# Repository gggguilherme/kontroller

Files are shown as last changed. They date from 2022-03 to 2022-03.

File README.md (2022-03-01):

# kontroller
 
this project is -getting on it's paces but hang in there, there's lots of work to do-
#
so proceed with caution and a lot of things might change

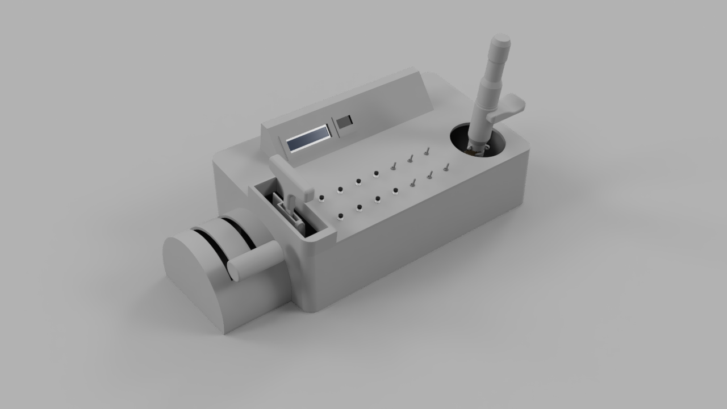
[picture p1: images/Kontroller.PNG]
Kontroller


# References
- [kRPC mod](https://www.github.com/krpc/krpc)
- [kOS mod](https://github.com/KSP-KOS/KOS)
- [LCD Display 3D Model](https://grabcad.com/library/16-x-2-lcd-display-module)
- [OLED Display 3D Model](https://grabcad.com/library/oled-128-x-64-display-1)
- [14 Segment Numerical Display 3D Model](https://grabcad.com/library/dual-digit-numeric-display-dc56-11-or-da56-11-1)
- [Trimmer Potentiometer 3D Model](https://grabcad.com/library/potentiometer-12)
- [Switch 3D Model 1](https://grabcad.com/library/small-power-switches-rocker-type-10-5x15mm-1)
- [Switch 3D Model 2](https://grabcad.com/library/spdt-print-toggle-switch-pcb-mount-1)
- [Buttons 3D Model](https://grabcad.com/library/lockless-on-off-push-button-switch-press-reset-switch-pbs-110-1)
- [G-Clamp 3D Model Thingiverse](https://www.thingiverse.com/thing:1673030)
- [Open Joystick](https://github.com/bhowiebkr/open-joystick)
(I took some ideas from open-joystick to design my stuff, it ended up being completely different, BUT I'd still like to share it because it's really cool and I learned stuff)

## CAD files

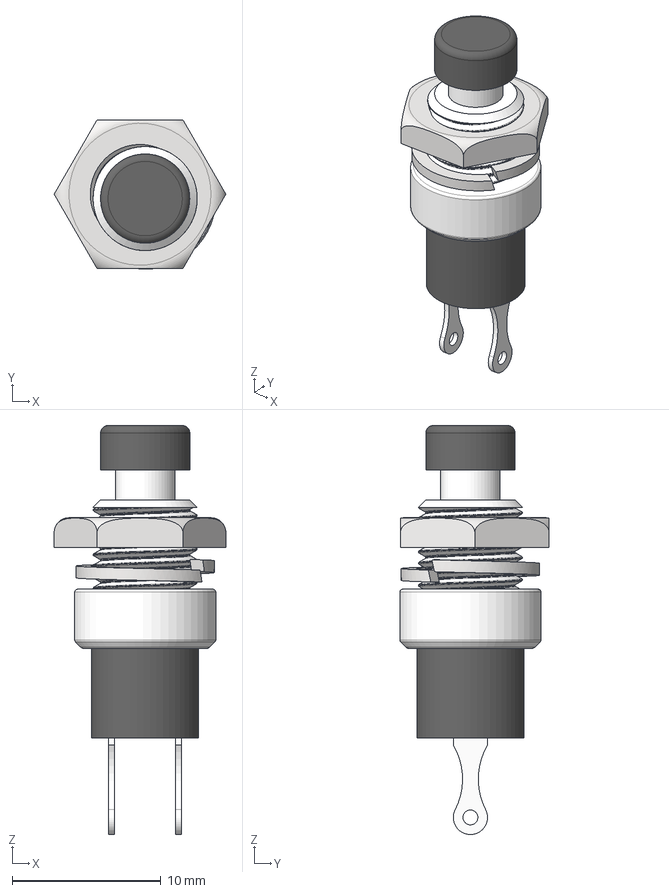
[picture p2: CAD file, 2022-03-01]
Source/3D Models/STEP/Imports/Push button Switch Press reset switch PBS-110.stp
11.5 x 10.0 x 27.5 mm
Self reset PBS-110 7mm Momentary Push button Switch
Nut_M7x0.75
Spring

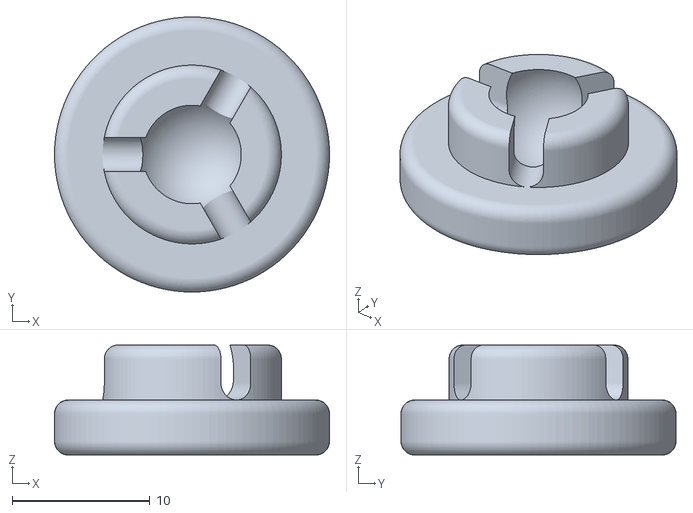
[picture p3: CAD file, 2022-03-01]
Source/3D Models/stl/3D Printed Clamp/clamp_protector.stl
20.0 x 20.0 x 8.00

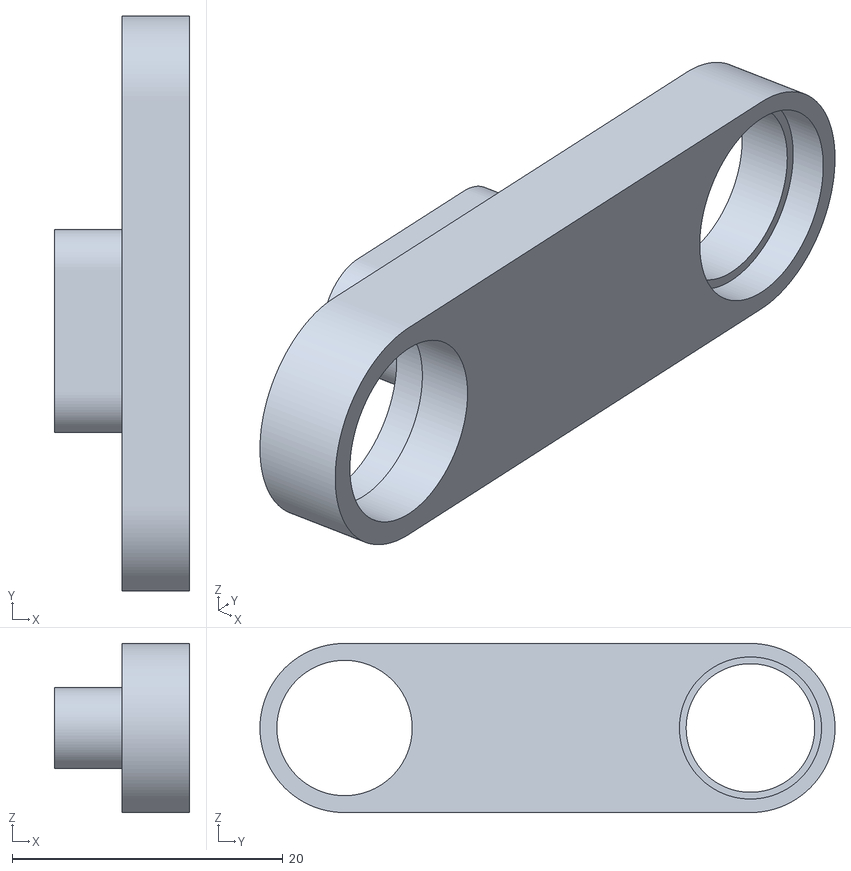
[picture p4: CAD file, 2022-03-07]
Source/3D Models/stl/Throttle Lever/Interface1.stl
10.0 x 42.5 x 12.5

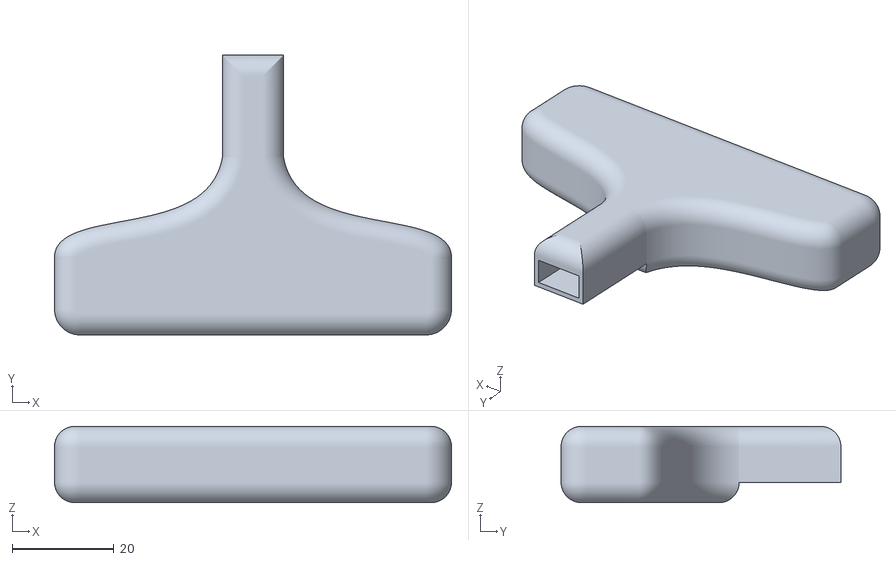
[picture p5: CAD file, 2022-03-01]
Source/3D Models/stl/Translation Control/Handle.stl
78.0 x 55.0 x 15.0

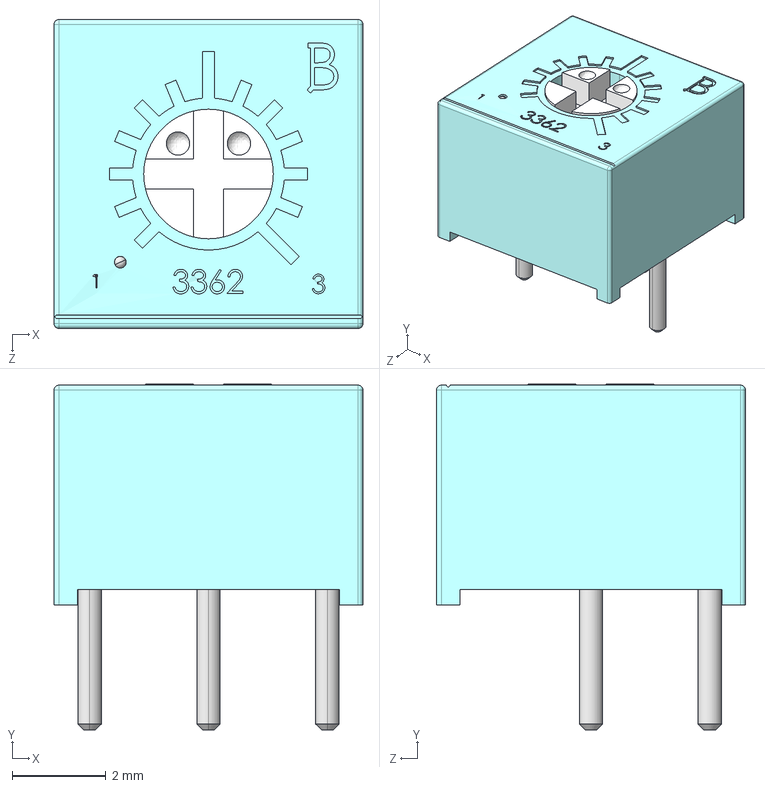
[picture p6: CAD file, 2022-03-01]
Source/3D Models/STEP/Imports/3362P-1-102LF.STEP
6.60 x 7.40 x 6.60 mm

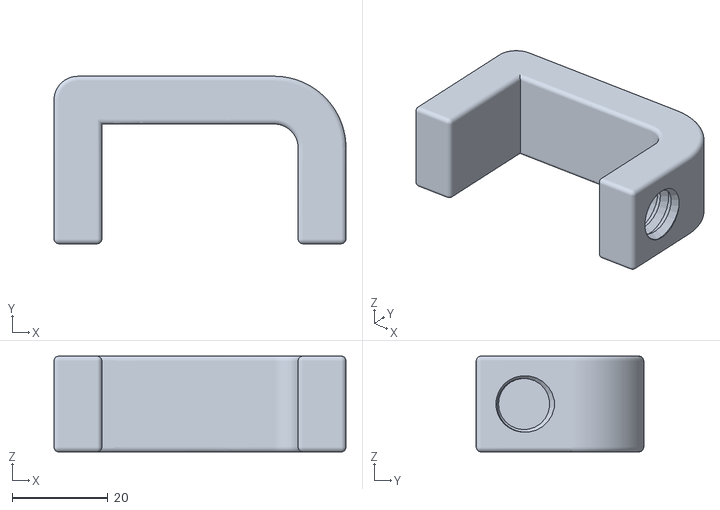
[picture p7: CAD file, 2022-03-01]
Source/3D Models/stl/3D Printed Clamp/clamp_frame.stl
61.0 x 35.0 x 20.0

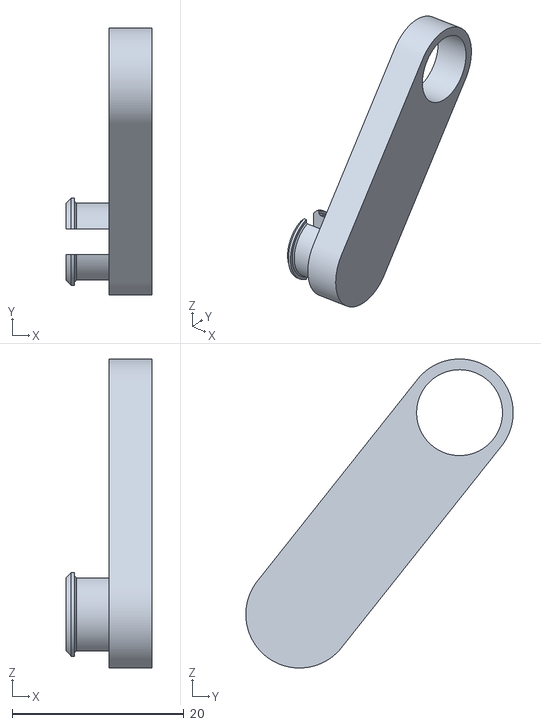
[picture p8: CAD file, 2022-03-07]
Source/3D Models/stl/Throttle Lever/Interface2.stl
10.0 x 31.2 x 36.0

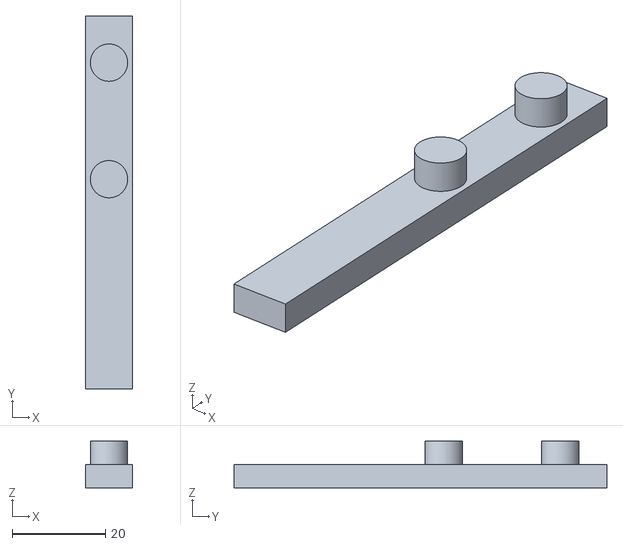
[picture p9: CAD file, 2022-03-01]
Source/3D Models/stl/Translation Control/X-Y Drive.stl
10.0 x 80.0 x 10.0

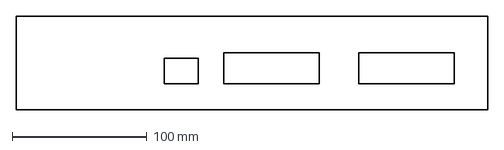
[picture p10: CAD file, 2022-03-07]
Source/Laser Cutting Files/Panel.dxf
350.0 x 69.3 mm

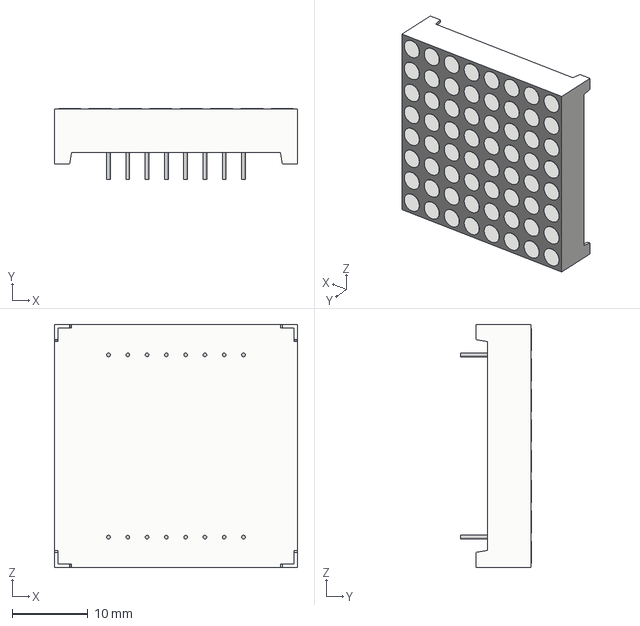
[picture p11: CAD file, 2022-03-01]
Source/3D Models/STEP/Imports/LED Matrix 3mm 8x8.step
32.0 x 9.30 x 32.0 mm

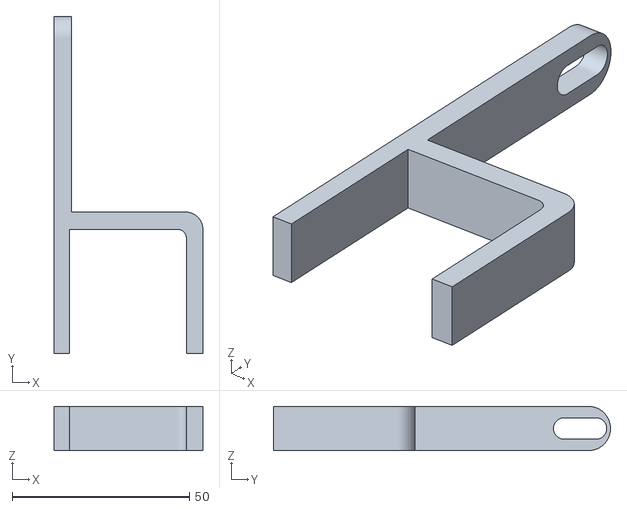
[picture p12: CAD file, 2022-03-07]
Source/3D Models/stl/Throttle Lever/Handle Adapter.stl
42.0 x 95.0 x 12.5

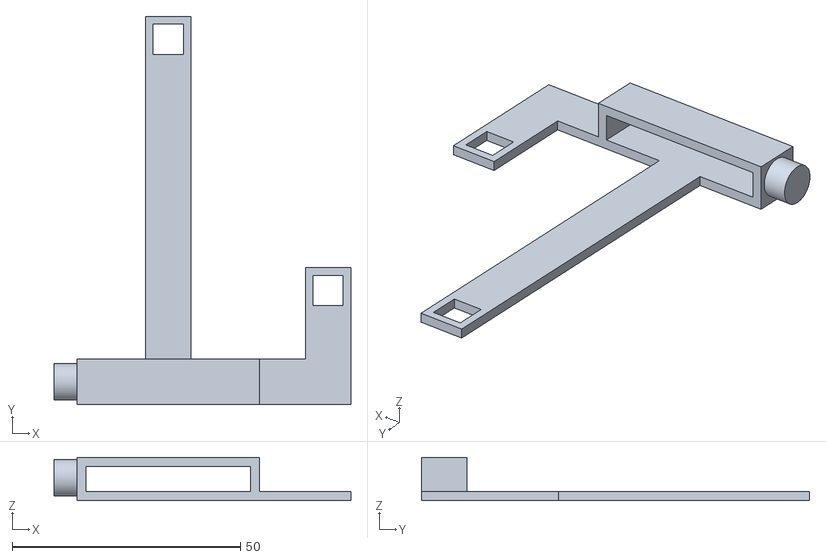
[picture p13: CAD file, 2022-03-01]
Source/3D Models/stl/Translation Control/Z Drive.stl
65.0 x 85.0 x 9.50

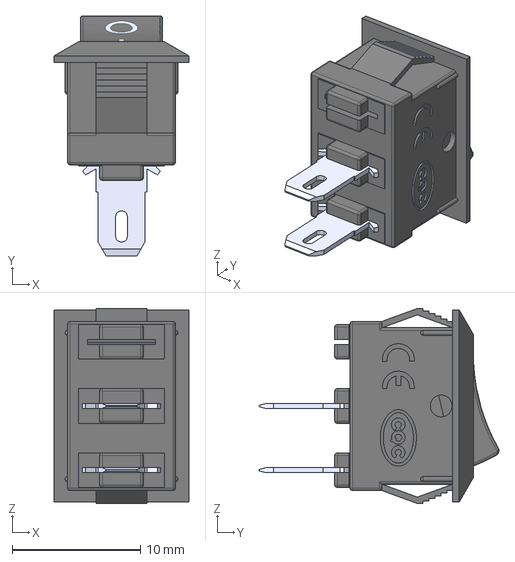
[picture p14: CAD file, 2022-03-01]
Source/3D Models/STEP/Imports/KCD1-11-2P-On.step
10.5 x 18.7 x 15.2 mm

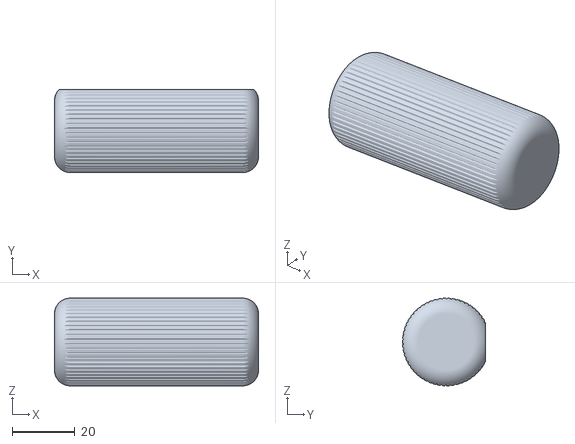
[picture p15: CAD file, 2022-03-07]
Source/3D Models/stl/Throttle Lever/Handle.stl
65.0 x 26.5 x 27.9

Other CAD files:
Source/3D Models/stl/Translation Control/Y Stick.stl
Source/3D Models/STEP/Imports/Display _ DC(DA)56-11.stp
Source/3D Models/stl/Throttle Lever/Interface3.stl
Source/3D Models/stl/Translation Control/Z Stick.stl
Source/3D Models/STEP/Imports/SPDT-Print-Switch.step
Source/3D Models/f3d/Kontroller parametric.f3z
Source/3D Models/stl/3D Printed Clamp/screw_and_knurled_knobHD.stl
Source/3D Models/stl/Translation Control/Pivot1.stl
Source/3D Models/stl/Translation Control/Pivot2.stl
Source/3D Models/stl/Translation Control/Support.stl
Source/3D Models/stl/Translation Control/X Stick.stl
Source/Laser Cutting Files/Panel(2).dxf

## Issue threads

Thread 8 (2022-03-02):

Throttle lever and translation pivot points fall appart

gggguilherme, 2022-03-02:
they fall appart- obviously because they have nothing that keeps them in place, while letting it move freely

gggguilherme, 2022-03-03:
working on this snap fit thing that locks the movement into the rotating axis

- [ ] test this new model
- [ ] if it works, implement changes from the throttle lever to the translation pivot points
the translation has this same issue, but it needs more work since it's way more joints to work with

gggguilherme, 2022-03-05:
still not testing because working on something else now hang on

gggguilherme, 2022-03-05:
it's tested
and it works!

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

now I'm going to implement this design to the translation control parts that need it

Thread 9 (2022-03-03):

it's really important to make parametric work with Fusion 360- I am not doing that right now

gggguilherme, 2022-03-03:
- [ ] remodel everything but make it with parameters (?)

ok that won't help future me-

make parameters for the snap fit joints I need for the translation and throttle lever- then work on everything else

gggguilherme, 2022-03-05:
doing it now!
the enclosure is now made with parameters, after the decision of making them laser cut instead of 3D printed, and should even be ready for cutting now. but I'm only doing it when the whole design is complete.

Closed 2022-03-07.

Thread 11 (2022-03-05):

so i bought a 16x2 lcd display and my bad soldering screwed with it

gggguilherme, 2022-03-05:
im sad i have to wait for another one to arrive and also i broke the cool awesome lcd display bruh oh no

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
ded

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
oh no

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
so this is the problem maybe- the soldering is very dirty and all over the place, so it shorts the circuit :(

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
the backlight doesn't even turn on AAAAA

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
my arduino wiring

gggguilherme, 2022-03-05:
ok I was dumb-

the backlight still works it was just my wiring

now I have a multimeter so it should be easy to debug whatever is wrong

the real problem happening is: black squares on first row
it's a very common problem with this, for my research

I'm going to check for every connection under my microscope to see if I left some soldering iron in between the pins

it's going to be okay

- [ ] it is okay

gggguilherme, 2022-03-05:
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

nvm anything I said- now it works
I just had to check the pins with the multimeter
there were no shorts

the problem were two wires i had to the data pins, they didn't work
threw them away and replaced

now it' okay :)

Closed 2022-03-05.

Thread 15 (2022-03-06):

list of needed hardware - prototype 1

gggguilherme, 2022-03-06:
### Important Tools

- access to a 3D printer
- access to a laser cutter
- soldering equipment

> All of these parts are just what I had laying around my workshop.
### Electronics

> This list is not yet complete

- Raspberry Pi Pico
- 2x LCD 16x2 Displays
- 1x Joystick module
- 1x Sliding potentiometer
- 1x Linear potentiometer 100k
- 1x Speaker/Buzzer
- 8x Push buttons
- 5x Switches with 3 positions
- 2x On/Off Switch
- Jumper wires
- PCBs and protoboards

### 3D Printed Parts
- Attitude Control Parts
- - Joystick handle and hand rest
- - Joystick Adapters for potentiometer and joystick module
- Throttle Lever Parts
- - Handle and Handle adapter
- - Interfaces parts with the sliding potentiometer
> I had to model these interface parts because I don't have enough regular rotating potentiometers.
- Internals
- - Raspberry Pi Pico support
- - Attitude control joystick support
- - Speaker support
- 3D Printed clamps (they clamp the kontroller to the desk)

### Laser Cut Parts
- Enclosure Parts (Left, right, front, back, bottom and panels)

### other parts
- lots of rubber bands / elastic for sewing (not really sewing)
- a sock
- super glue

> **_This is open source for all to use, obviously, not everybody on the planet has a bunch of junk in their workshop to make something like this._**

Having said that, since this is open source, if you are going to make something based on this project, you should have all the skills to edit the provided files in this repository to fit your needs and what you have.

(adding more stuff while I work out what this release needs)

gggguilherme, 2022-03-16:
added to documentation
[Wiki](https://github.com/gggguilherme/kontroller/wiki/Hardware-List)

Closed 2022-03-16.

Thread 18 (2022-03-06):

Figure out how to use a raspberry pi pico with projects

gggguilherme, 2022-03-06:
I have a raspberry pi pico, and it will be nice to use it because it's way more capable than my arduinos (for what I'm told), also for learning experience

> Steps

- [x] soldering the pins into the Pico's pins
- [x] blinking leds and testing
- [x] work with arduino IDE and c++
- [x] work with kRPC library

gggguilherme, 2022-03-07:
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

Very successful first tests!

learned more soldering and managed to hook up the LCD Display

this was my first try with the raspberry pi pico and I'm happy with it

now I want to test it with kRPC

gggguilherme, 2022-03-16:
so it's now done, I learned how to use the pi pico and the LCD displays. horray!

Closed 2022-03-16.

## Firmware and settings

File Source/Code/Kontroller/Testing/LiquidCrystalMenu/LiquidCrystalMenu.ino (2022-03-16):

#include <LiquidMenu.h>
#include <krpc.h>
#include <krpc/services/space_center.h>

// Starting lcds
const int rs1 = 12, en1 = 11, d41 = 5, d51 = 4, d61 = 3, d71 = 2;
const int rs2 = 35, en2 = 37, d42 = 41, d52 = 43, d62 = 45, d72 = 47;

LiquidCrystal lcd1(rs1, en1, d41, d51, d61, d71);
LiquidCrystal lcd2(rs2, en2, d42, d52, d62, d72);

//Defining variables that will be updated later
char* vesselStatus;
char* vesselName;
float vesselMass = 23.31;
float vesselDeltaV = 403.3;
double vesselAltitude =  64.0;
bool vesselIsRecoverable = true;
float distanceToKSC = 532.0;
char* vesselBiome;
float vesselPeriapsis = 0.0;
float vesselApoapsis = 0.0;

String current_display_state = "Vessel";

bool iskRPCConnected;

//Main Menu

//Welcome Screen
LiquidLine welcome1(0, 0, "Kontroller");
LiquidLine welcome2(0, 1, "Kerbal Space Program");
LiquidLine welcome3(0, 2, "Starting...");
LiquidLine welcome4(0, 3, "2022 by @g");
LiquidScreen welcomeScreen(welcome1, welcome2, welcome3, welcome4);
//Vessel Screen
LiquidLine statusLine(0, 0, "Status:", vesselStatus);
LiquidLine nameLine(0, 1, "Name:", vesselName);
LiquidLine massLine(0, 2, "Mass:", vesselMass);
LiquidLine deltaVLine(0, 3, "dV:", vesselDeltaV);
LiquidScreen vesselScreen(statusLine, nameLine, massLine, deltaVLine);

//Data Showing Menu

//Position Landed1 Screen
LiquidLine altitudeLine(0, 0, "Alt:", vesselAltitude, "m");
LiquidLine isRecoverableLine(0, 1, "Recoverable:", vesselIsRecoverable);
LiquidScreen vesselScreenPositionLanded1(altitudeLine, isRecoverableLine);

//Position Landed2 Screen
LiquidLine KSCDistanceLine(0, 0, "KSC:", distanceToKSC, "m");
LiquidLine biomeLine(0, 1, "Biome:", vesselBiome);
LiquidScreen vesselScreenPositionLanded2(KSCDistanceLine, biomeLine);

//Position Orbiting1 Screen
LiquidLine periapsisLine(0, 0, "Pe:", vesselPeriapsis);
LiquidLine apoapsisLine(0, 0, "Ap:", vesselApoapsis);
LiquidScreen vesselScreenPositionOrbiting1(periapsisLine, apoapsisLine);

/*
  LiquidScreen vesselScreenPositionOrbiting2();
  LiquidScreen vesselScreenPositionFlying();
  LiquidScreen vesselScreenPositionRoving();
  LiquidScreen vesselScreenPositionSubOrbital();
*/

LiquidLine isConnectedLine(0, 0, "Is connected:", iskRPCConnected);
LiquidLine connectButton(0, 3, "CONNECT");
LiquidScreen kRPCScreen(isConnectedLine, connectButton);


// Declaring Menus
LiquidMenu menu1(lcd1, welcomeScreen, kRPCScreen, vesselScreen, 1);
LiquidMenu menu2(lcd2, vesselScreenPositionLanded1, 1);
/*
  menu2.add_screen(vesselScreenPositionOrbiting2);
  menu2.add_screen(vesselScreenPositionFlying);
  menu2.add_screen(vesselScreenPositionRoving);
  menu2.add_screen(vesselScreenPositionSubOrbital);
*/

//Button Handling
#define BUTTON_R_PIN 9
#define BUTTON_L_PIN 8

int button_r_hold;
int button_l_hold;
bool button_r_released;
bool button_l_released;

//temporary for button visualization on displays
LiquidLine buttonLine(0, 0, "button:", button_r_hold);
LiquidScreen buttonScreen(buttonLine);

//kRPC Initialization
HardwareSerial* conn;

void cycle_current_data_screens()
{
  return;
}

void krpc_get_shown_data()
{
  if (current_display_state == "Vessel")
  {
    krpc_SpaceCenter_Vessel_t vessel;
    krpc_SpaceCenter_Flight_t flight;
    krpc_SpaceCenter_ActiveVessel(conn, &vessel);
    krpc_SpaceCenter_ReferenceFrame_t reference;
    krpc_SpaceCenter_Vessel_Flight(conn, &flight, vessel, krpc_SpaceCenter_Vessel_SurfaceReferenceFrame(conn, &reference, vessel));


    krpc_SpaceCenter_Vessel_Name(conn, &vesselName, vessel);
    //krpc_SpaceCenter_Vessel_Situation(conn, &vesselStatus, vessel);
    krpc_SpaceCenter_Vessel_Mass(conn, &vesselMass, vessel);

    krpc_SpaceCenter_Vessel_Recoverable(conn, &vesselIsRecoverable, vessel);
    krpc_SpaceCenter_Flight_MeanAltitude(conn, &vesselAltitude, vessel);
    distanceToKSC = 532.0;
    vesselBiome = "Shores";
    vesselPeriapsis = 0.0;
    vesselApoapsis = 0.0;
  }
}

void connect_to_krpc()
{
  conn = &Serial;

  krpc_open(&conn, NULL);
  krpc_connect(conn, "Kontroller");

  iskRPCConnected = true;
}

void setup() {
  lcd1.begin(20, 4);
  lcd2.begin(16, 2);
  //  menu2.add_screen(vesselScreenPositionLanded2);
  //  menu2.add_screen(vesselScreenPositionOrbiting1);
  menu2.add_screen(buttonScreen);
  menu1.update();
  menu2 .update();

  delay(3000);
  menu1.next_screen();
  menu2.next_screen();
  menu2.update();
  menu1.update();

  connectButton.attach_function(0, connect_to_krpc);
}

int _millis = millis();
int __millis = millis();
int ___millis = millis();


void loop() {
  if (millis() - _millis > 1000)
  {
    krpc_get_shown_data();
    menu1.update();
    menu2.update();
    _millis = millis();
  }

  if (millis() - __millis > 5000)
  {
    cycle_current_data_screens();
    __millis = millis();
  }

  bool button_r_read = digitalRead(BUTTON_R_PIN);
  bool button_l_read = digitalRead(BUTTON_L_PIN);

  //getting if buttons are pressed and for how long
  if (button_r_read)
  {
    button_r_hold = millis() - ___millis;
  }
  else
  {
    button_r_hold = -1;
    ___millis = millis();
  }
  if (button_l_read)
  {
    button_l_hold = millis() - ___millis;
  }
  else
  {
    button_l_hold = -1;
    ___millis = millis();
  }

  //right button interactions
  if (button_r_hold < 500 && button_r_hold != -1)
  {
    menu1.switch_focus(true); //switch line focus foward
  }
  else // if it's a longer press
  {
    menu1.call_function(0);
  }
  // left button interactions
  if (button_r_hold < 500 && button_r_hold != -1)
  {
    menu1.switch_focus(false); //switch line focus backward
  }
  else // if it's a longer press
  {
    menu1.previous_screen();
  }
}

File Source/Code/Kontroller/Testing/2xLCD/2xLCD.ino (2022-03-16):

#include "Display.h"
#define BUTTON1_PIN 9
#define BUTTON2_PIN 8

const int rs1 = 15, en1 = 14, d41 = 13, d51 = 12, d61 = 11, d71 = 10;
const int rs2 = 16, en2 = 17, d42 = 18, d52 = 19, d62 = 20, d72 = 21;

Display lcd1(rs1, en1, d41, d51, d61, d71, 20, 4);
Display lcd2(rs2, en2, d42, d52, d62, d72, 16, 2);

void setup() {
  Serial.begin(9600);
  lcd1._init();
  lcd2._init();
}

void loop() {
  lcd1._loop();
  lcd2._loop();
}

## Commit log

2022-02-20 Version 1 of joystick gimbal
    [FixedRig.3mf, Gimbal.3mf, Joystick Gimbal v1.step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]
2022-02-20 trying to 3d print the bearings
    [homemade_printable_bearing_heavy_small_V2.stl, homemade_printable_bearing_heavy_small_V3_easy_printable.stl]
2022-02-21 docs updated
    not docs really, it's just feature planner in case I lose track of what I'm really doing with this project.
2022-02-21 new 3D Models for testing
    these are much simpler than the previous version, because it will use the joystick module potentiometer, and another regular linear potentiometer which is MUCH simpler than making a complicated mechanism for this movement, the next step is to figure out a way to make this stable to the center, so it doesn't drift like other poorly made joysticks (roasted) which could be solved with a complicated mechanism but i think just adding rubber bands solves this in a jiff
    [Adapter1.3mf, Adapter2.3mf, Attitude Control Base v1.step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]
2022-02-22 modelling attitude controller
    [Attitude Control v3.step]
2022-02-24 Parts for joystick system modeled and tested
    [Adapter1 v2.3mf, Adapter2 v2.3mf, Adapter3 v2.3mf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]
2022-02-24 3D Cad files
    [Attitude Control v9.f3d, Attitude Control v9.step]
2022-02-24 3D Cad Files for Kontroller
    [Kontroller v3.f3z, Kontroller v3.step]
2022-02-26 Joystick Modeled!
    [JostickAdapter1.3mf, Joystick Handle.3mf, Joystick-HandRest.3mf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]
2022-02-26 Throttle Modeled!
    [Handle.3mf, HandleAdapter.3mf, Pivot1.3mf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]
2022-02-26 not needed files deleted
    [Joystick-Left.3mf, Joystick-Right.3mf, spacer.3mf]
2022-02-26 f3d files for the Kontroller full concept and translation mechanism
    [Kontroller.f3z, Translation.f3d]
2022-02-27 saving f360 files
    for reworking the 3d models again, with the imported 3d models and new ideas
    [Attitude Control v21.f3d, Button Panel v18.f3d, Kontroller v13.f3z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]
2022-02-27 deleted stuff and imported files
    imported: LCD 16x2 Display and potentiometer 3362
    [3362P-1-102LF.STEP, 608zz_mk2_Standard-10.stl, Adapter1 v2.3mf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]
2022-02-28 bunch of models imported
    files:
    14 seg display
    led matrix display
    on-off switch
    buttons
    switches
    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
    [Display _ DC(DA)56-11.stp, KCD1-11-2P-On.step, LED Matrix 3mm 8x8.step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]
2022-03-01 Translation Control stl
    [Support.stl, X Stick.stl, X-Y Drive.stl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]
2022-03-01 Throttle Lever stl
    [Handle Adapter.stl, Handle.stl, Interface1.stl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]
2022-03-01 Throttle Lever Interface3 redesign
    -it seems the file was actually much different than what I actually designed and I'm going to fix it soon-
    [Interface3.stl]
2022-03-03 modelling a pivot point that locks with a rotating axis
    not done yet still testing but idk this is difficult man
    [Handle Adapter.stl, Handle.stl, Interface1.stl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]
2022-03-04 Create Kontroller parametric.f3z
    this file will be the new main modelling file, and I'll make it parametric in case I need to change stuff in the future and not get screwed
    [Kontroller parametric.f3z]
2022-03-05 stls for throttle lever interface
    [Handle Adapter.stl, Interface3.stl]
2022-03-07 kRPC arduino testing
    making rpc calls and getting altitude reading to show on lcd display
2022-03-07 Laser cutting dxf files
    files for the main panel of controller
    these were just for testing inkscape actually
    [Panel(2).dxf, Panel.dxf]
2022-03-10 lcd displays work
    using oop to make something cool but it's not working yet so no pushes- just finishing work for today
    [2xLCD.ino]
2022-03-15 OH MY GOD it's finally over
    basically I had a really annoying problem with the pi pico that lasted a few days and now it works, kinda
    [LCDMenus.ino, LiquidCrystalMenu.ino]
2022-03-16 LCD displays menu interactions
    still testing: attachFunction and callFunction methods
